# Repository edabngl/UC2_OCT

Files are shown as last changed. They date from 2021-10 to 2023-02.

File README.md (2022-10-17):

<p align="center">
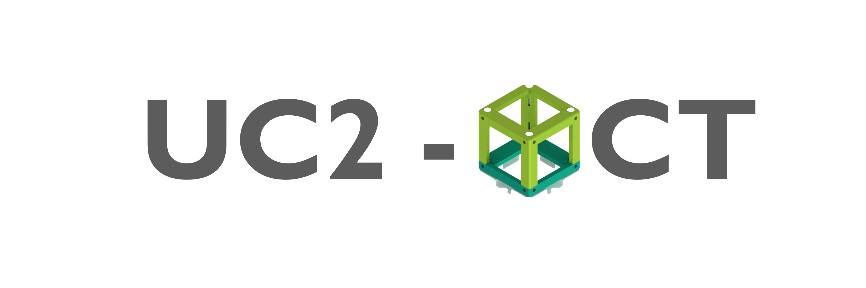
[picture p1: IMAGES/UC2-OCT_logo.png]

</p>

# Open-Source, Low-Cost, 3D-Printed, Full-Filled Time-Domain Optical Coherence Tomography using openUC2 Modular System
---
__*The project contents are still updating. Last update is in 17.10.2022.*__

This repository will help you to build and setup *UC2-OCT*.

In this project, we will design a open-source, low-cost, 3D-printed, Full-filled Time-domain Optical Coherence Tomography based on UC2 optical system.
The setup uses 3D-Printed inserts and cubes, Injection Molding (IM) cubes and cheap optical and electronic components. Some module designs were used directly from UC2-v3 designs, and some of them were redesigned for the UC2-OCT setup.

***Key Parameters of the UC2-OCT Project:***
* The system is Low-cost : 3D-Printed inserts, IM cubes and cheap components
  *  cheap Light Source (LaserLand RGB laser and Superlum SLD at 850 nm)
  *  cheap optical filters (Comar Longpass Filter)
  *  cheap Detector (RasPi camera and Raspi 4)
  *  cheap electronics (ESP-32S as microcontroller)
  *  low-cost, light Silver Mirror (DIY)
* Easy to assemble: 3D-printed cubic modular sytem
* Open-Source: UC2 based system and publishing all details online in GitHub repository
* 3D-Printed: UC2 based experimental setup

### THEORY

This section introduces the theoretical part of the *UC2-OCT* project. It will help you to understand the basic physics behind the setup. The setup is built using 3d-printed modular optical toolbox system openUC2. The details of the project is explained in its [GitHub](https://github.com/openUC2/UC2-GIT) repository in detail.

The basic parameteres of 3d-printed and IM base cubes are explained [here](https://github.com/openUC2/UC2-GIT/tree/master/CAD/ASSEMBLY_CUBE_Base). OCT is based on Michelson Interferometer system and it was already adapted and tested in [UC2](https://github.com/openUC2/UC2-GIT/tree/master/APPLICATIONS/APP_Michelson_Interferometer) design system.

##### Optical Coherence Tomography (OCT)

The following sketch demonstrates the basic OCT scheme based on time.
<p align="center">
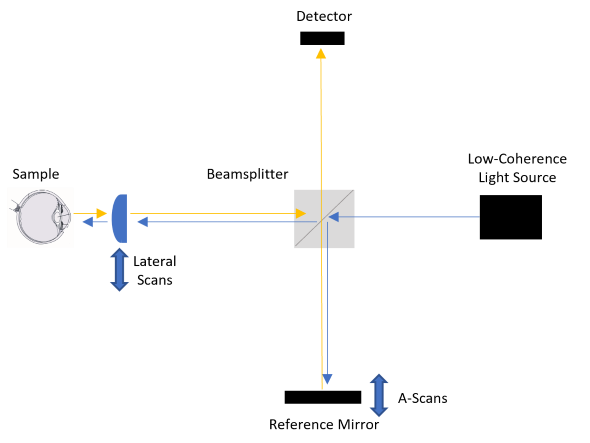
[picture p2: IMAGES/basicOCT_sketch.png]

</p>
##### Full-filled Optical Coherence Tomography (FF-OCT)
*Working Principle:* FF-OCT employs a 2-D image sensor like a CCD or CMOS camera as the detector, and en-face images of the sample are acquired at different depths by coherence gating.

* High axial and lateral resolutions are possible with FF-OCT.
* The use of FF-OCT in the time-domain configuration avoids specialized and potentially expensive components such as galvanometer or MEMS micromirror scanners, swept-sources and even superluminescent diode (SLED) or halogen or supercontinuum sources. Simple LEDs provide sufficient illumination for sub-10-μm imaging. Such a system has the potential to create high resolution 3D tomograms at very low cost.

REFERENCE:
Invented by Claude Boccara in 1998 (France).
Resolution: 1um in 3D

The full-filled OCT (FF-OCT) setup give an opportunity of recording en-face images of the sample when the Reference mirror moves in the z-axis. The movement mechanism of the sample Objective lens is not needed in time-domain designs and the technique enables the high-speed OCT scanning with its this advantage. The working mechanism of the FF-OCT can be shown in the figure below.

<p align="center">
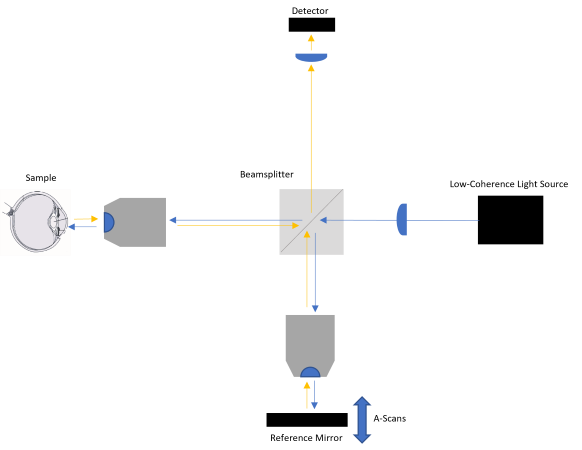
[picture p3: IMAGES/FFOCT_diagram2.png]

</p>

### UC2-OCT

*UC2-OCT Setup Diagram*

__Sketch 1__ describes the OCT system with red laser and SLD light sources.   The experimental procedure starts with the laser source and then switches to SLD source. Basic idea of aligning with Laser is the setting up the mirrors and objective lenses positions in Sample Arm and Reference arm using the advantage of the long coherence length of the laser source.
SLD diode is a low-coherence light. The aligned setup is directly used with NIR-SLD light source. The details of the setup design and experimental steps are explained in the [Experimental Process section](./1.Experimental_Process).

<p align="center">
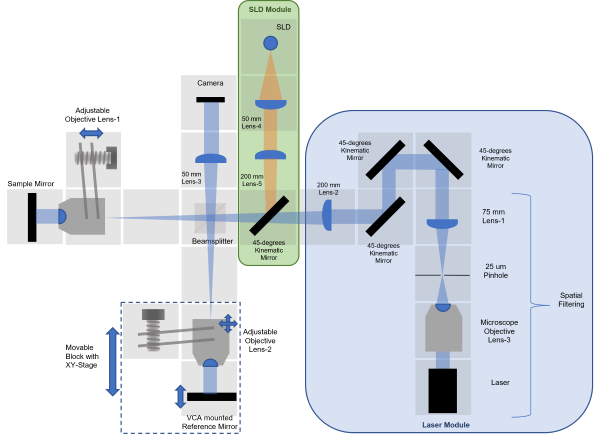
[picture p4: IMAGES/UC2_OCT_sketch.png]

</p>

*UC2-OCT Setup Diagram (adapted to Autodesk Inventor with UC2 modules)*

<p align="center">
<a href="#logo"
name="logo">
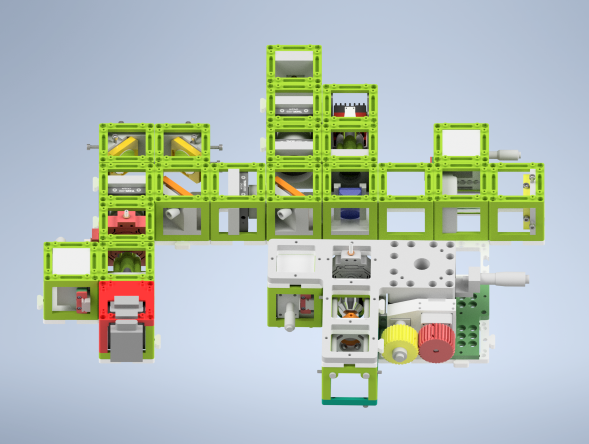
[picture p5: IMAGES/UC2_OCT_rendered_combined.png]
</a>
</p>

## Table of Content
  * **[1. Experimental Process](./1.Experimental_Process)**
    * **[Modules](./2.Experimental_Process/Modules)**
    * **[Alignment Procedure](./1.Experimental_Process/Alignment_Procedure)**
    + **[4. Bill of Materials](./1.Experimental_Process/Bill_of_Materials)**
  * **[2. Results](./2.Results)**

## Get Involved
This project is open so that anyone can get involved. You don't even have to learn CAD designing or programming.
You can directly connect with us using GitHub repository. Ask your questions or share your ideas with us!

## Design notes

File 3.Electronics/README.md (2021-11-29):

# Electronics

During the project, some electronic parts are using for various purposes.

Laser in the system is used for alignment of the mirrors.
LED is the light source of the setup.
Voice Coil Actuator (VCA) is used in different modules for linear motion of the sample in z direction and fine adjustment of the reference mirror.
Camera records the A-scan and B-scan images.

For more details, check the folder of each electronic parts.
* [LED Light Source](./3.Electronics/LED)
* [LASER](./3.Electronics/LASER)
* [SLED](./3.Electronics/SLED)
* [Voice Coil Actuator](./3.Electronics/Voice_Coil_Actuator)
* [Camera](./3.Electronics/Camera)

## Collaborating
If you find this project useful, please like this repository, follow us on Twitter and cite the webpage! :-)

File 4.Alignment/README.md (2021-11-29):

# Alignment Procedures

This repository will help you to build and alignment process of *UC2-OCT*.

*In this project, we will design a low-cost, 3D-printed, time-domain Optical Coherence Tomography based on UC2 system.*
We started to build our setup with basic version; Michelson Interferometer. Then, the setup will be adapted to the UC2 System with 3D-Printed inserts, Injection Molding (IM) cubes and cheap components.

## Alignment Procedure of Michelson Interferometer with Laser

I used different articles to follow in the alignment process.
_1st article_ is [](). In this article 2 important steps of the alignment process is explained in detail. Our aim is to see interference fringes. To make the process easier I prefered to used [RGB Laser](.../3.Electronics/LASER)

Reference Article: [An improved Michelson interferometer: smoothing out the rough spots for a more effective teaching tool - 2021](https://www.spiedigitallibrary.org/conference-proceedings-of-spie/10452/104521H/An-improved-Michelson-interferometer--smoothing-out-the-rough-spots/10.1117/12.226966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)

* 1st step is

_2nd technic_ is observing Fresnel Interference to obtain almost same arm distances for two mirrors.
(Rainer's suggestion)
Reference Article:[Fresnel Interference in the Michelson Interferometer - 1950](https://www.osapublishing.org/josa/abstract.cfm?uri=josa-40-11-787)

## Project Timeline:

| Date | To Do | Status of the Task |
| --- | --- | --- |
| **September 2021** | Using Thorlab equipments, Michelson Interferometer was built with a RGB Laser and Red paper filter. | `DONE` |

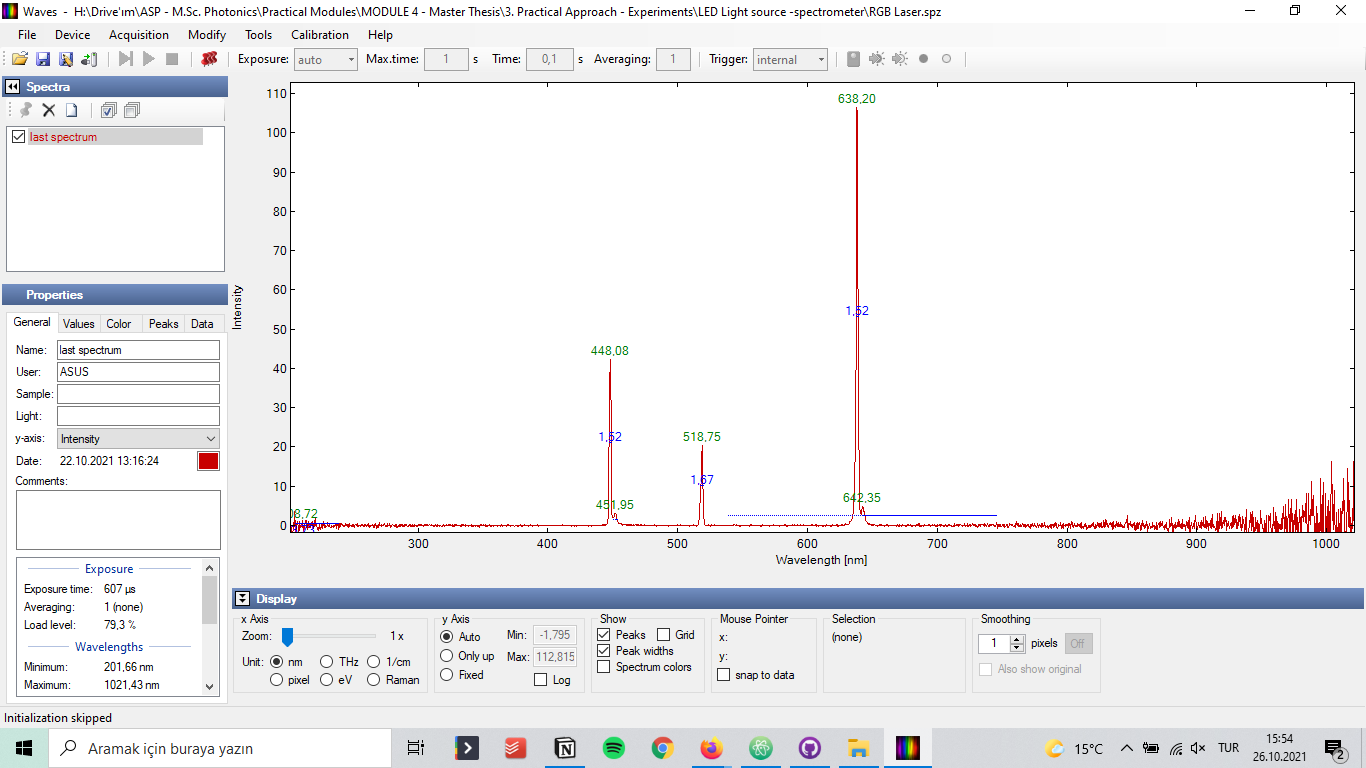
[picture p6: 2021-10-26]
1.Experimental_Process/Modules/1.Light Source Modules/1.LASER/IMAGES/RGB Laser spectrum.PNG

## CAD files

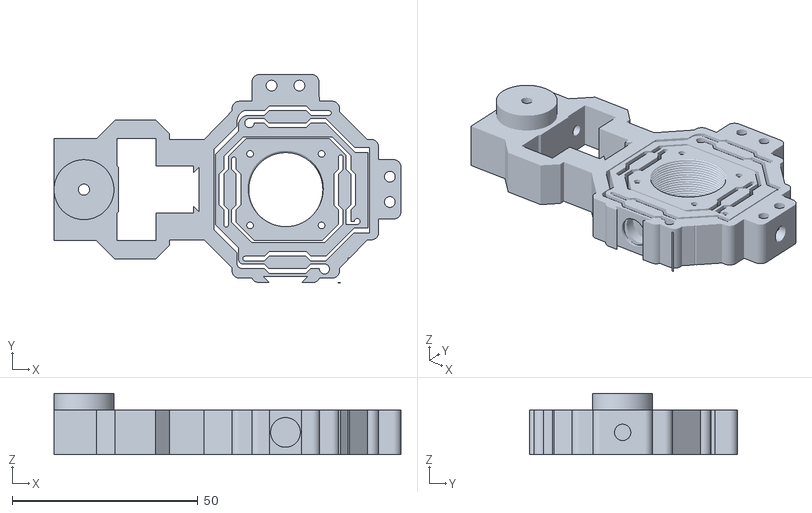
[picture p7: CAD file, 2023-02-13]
1.Experimental_Process/Modules/4.Adjustable Z Stage Modules/XZ directions/Assembly_Cube_Z_Stage_Objective_XY_Stage.stl
93.3 x 56.0 x 16.5

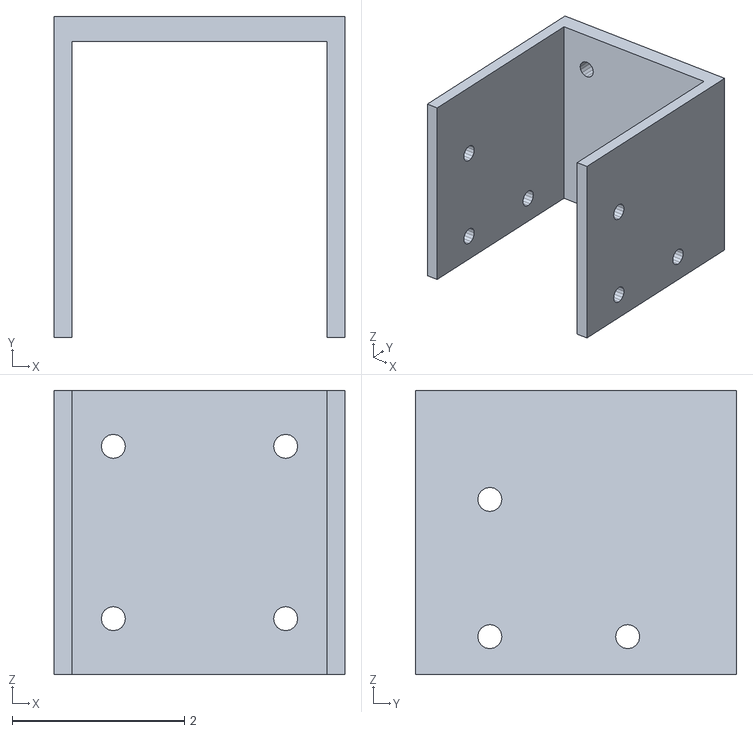
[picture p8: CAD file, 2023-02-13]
1.Experimental_Process/Modules/1.Light Source Modules/1.LASER/DESIGN FILES/Assembly_Cube_Laser_Multicolour_insert_v3.stl
3.37 x 3.73 x 3.30

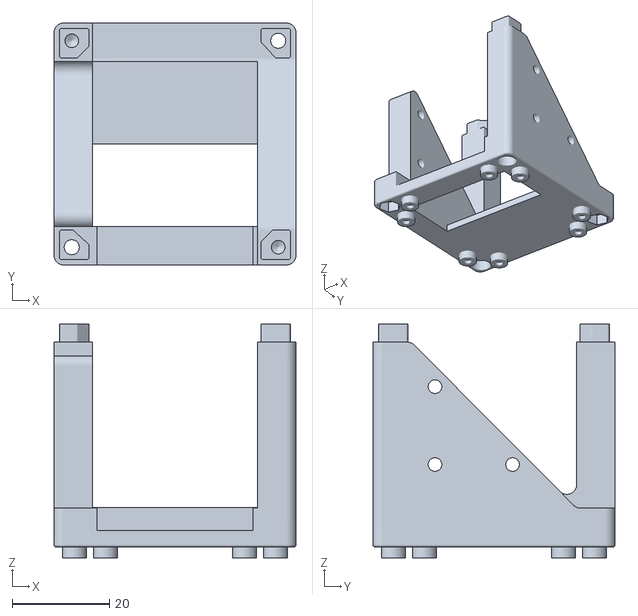
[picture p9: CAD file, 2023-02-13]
1.Experimental_Process/Modules/1.Light Source Modules/1.LASER/DESIGN FILES/20_Cube_Insert_Laser_multicolour_Lid_v3.stl
49.7 x 49.7 x 48.0

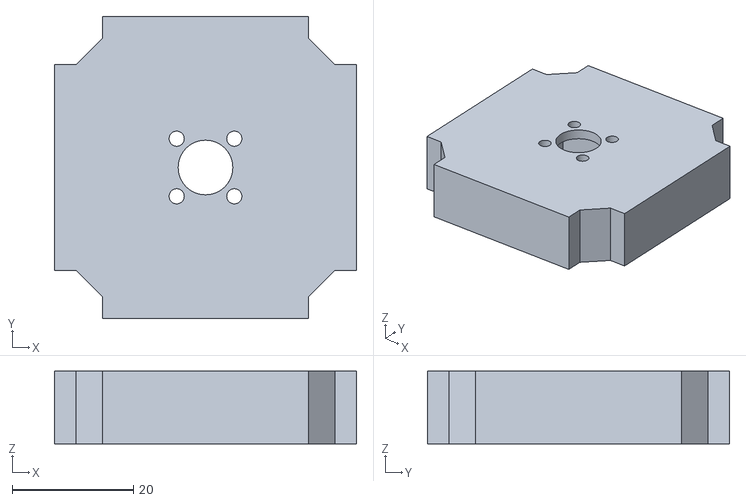
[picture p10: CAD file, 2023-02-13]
1.Experimental_Process/Modules/1.Light Source Modules/2.SLD/DESIGN FILES/20_Cube_Insert_Lasertack_mount_v3.stl
49.8 x 49.8 x 12.0

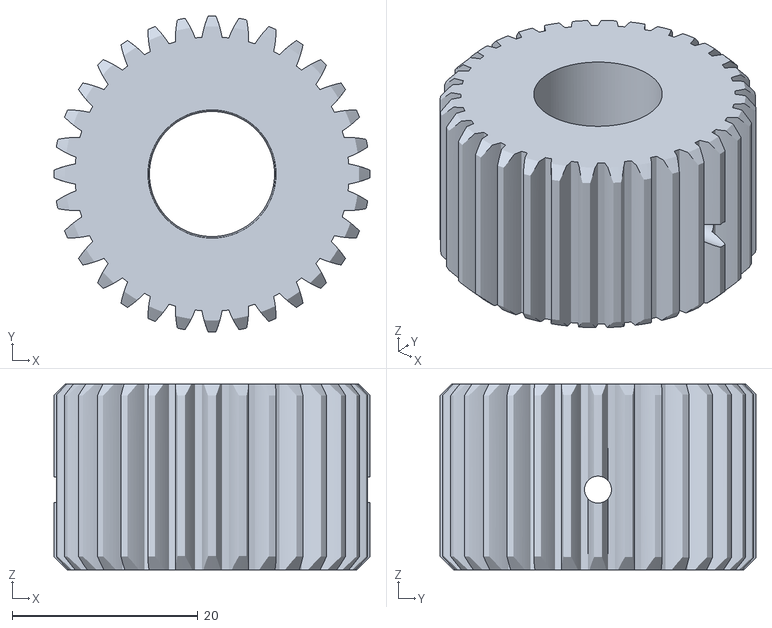
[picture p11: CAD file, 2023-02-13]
1.Experimental_Process/Modules/10.XY Linear Stage with Motors/30_cellSTORM_UC2_motorized_micrometer_gear2.stl
34.0 x 34.0 x 20.0

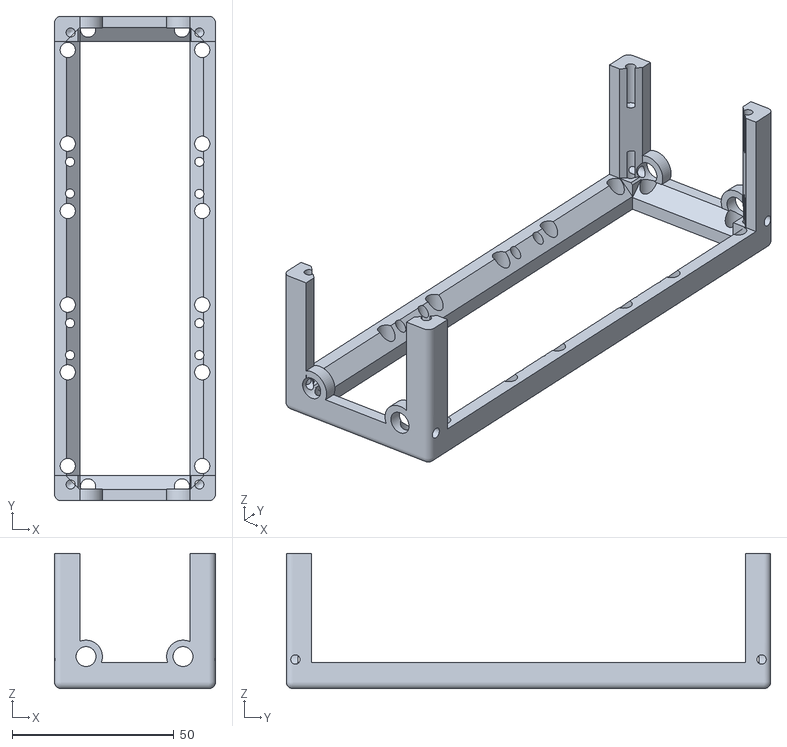
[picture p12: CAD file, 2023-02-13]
1.Experimental_Process/Modules/11.Base Cube and Others/10_Cube_3x1_with_rodes_v3.stl
49.8 x 149.8 x 41.8

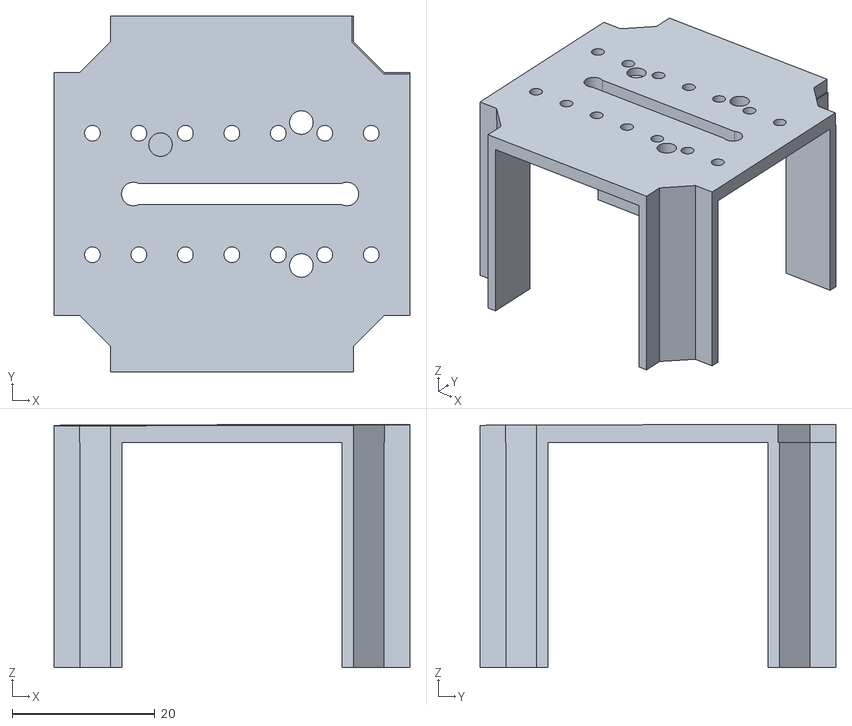
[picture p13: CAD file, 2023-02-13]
1.Experimental_Process/Modules/2.Camera Module/20_Cube_insert_AlliedVision_Alvium_v3.stl
49.8 x 49.8 x 34.0

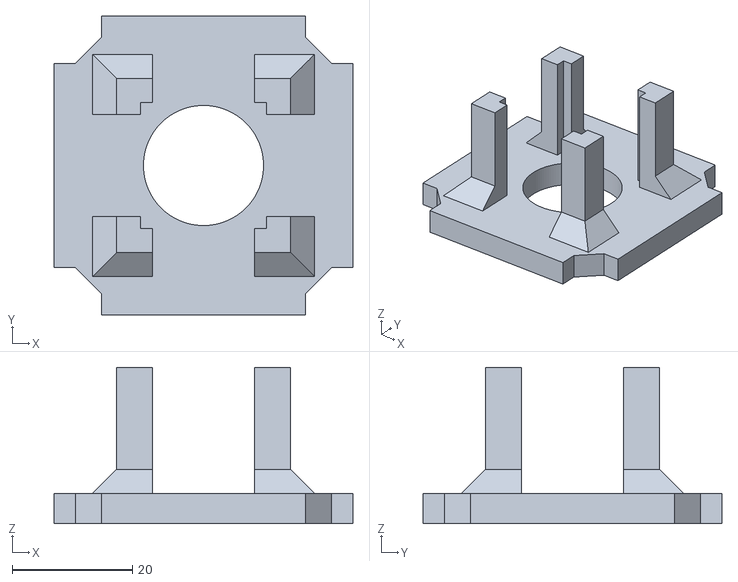
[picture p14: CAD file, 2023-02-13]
1.Experimental_Process/Modules/3.Beamsplitter Module/20_Cube_Insert_Beamsplitter_v3.stl
49.8 x 49.8 x 26.0

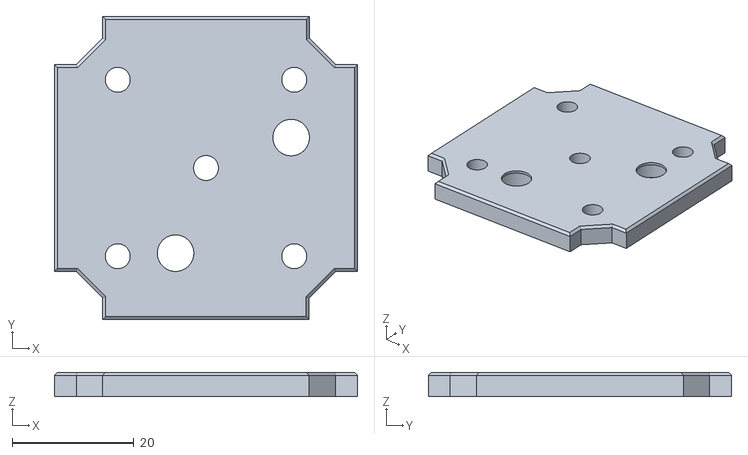
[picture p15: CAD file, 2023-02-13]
1.Experimental_Process/Modules/5.Sample Mirror Holder Module/20_Cube_Insert_Kinematic_Mirror_90_pro_magnetic_thin.stl
49.8 x 49.8 x 4.00

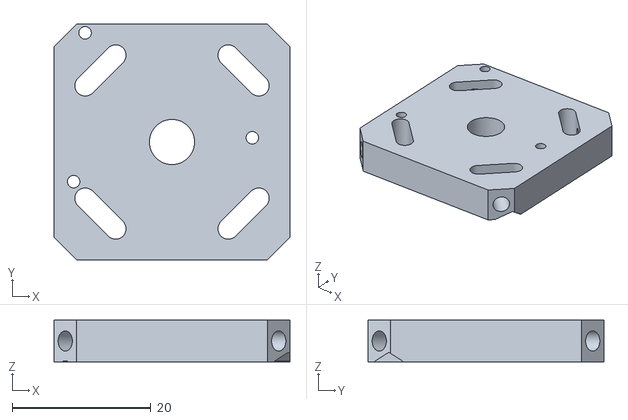
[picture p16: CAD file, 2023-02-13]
1.Experimental_Process/Modules/6.Reference Mirror Module/KES400 VCA/20_Cube_Insert_Kinematic_KES400_VCAmount__90_pro_v3_rod.stl
34.0 x 34.0 x 6.00

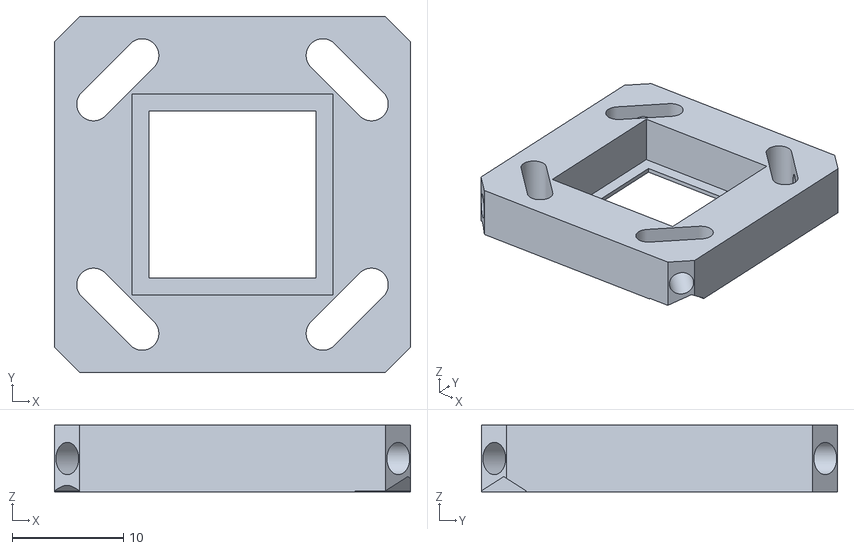
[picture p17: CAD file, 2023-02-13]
1.Experimental_Process/Modules/6.Reference Mirror Module/M12 VCA/20_Cube_Insert_Kinematic_M12_VCAmount__90_pro_v3.stl
32.0 x 32.0 x 6.00

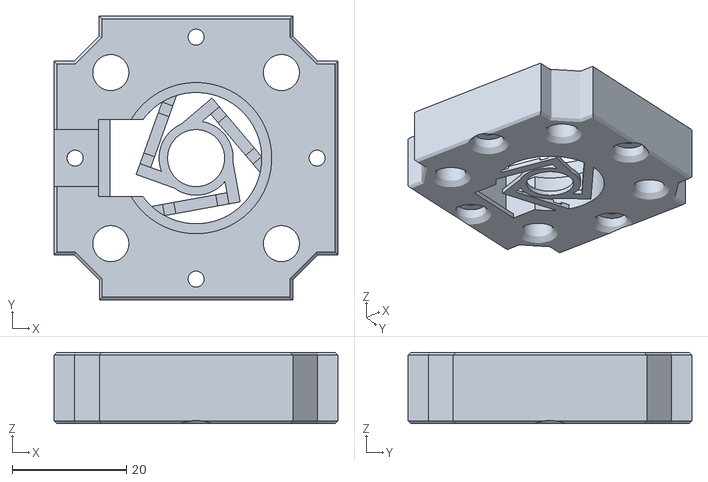
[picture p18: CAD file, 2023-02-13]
1.Experimental_Process/Modules/6.Reference Mirror Module/UC2 VCA/20_Cube_Insert_VCA_base_upper_v0.stl
49.8 x 49.8 x 12.5

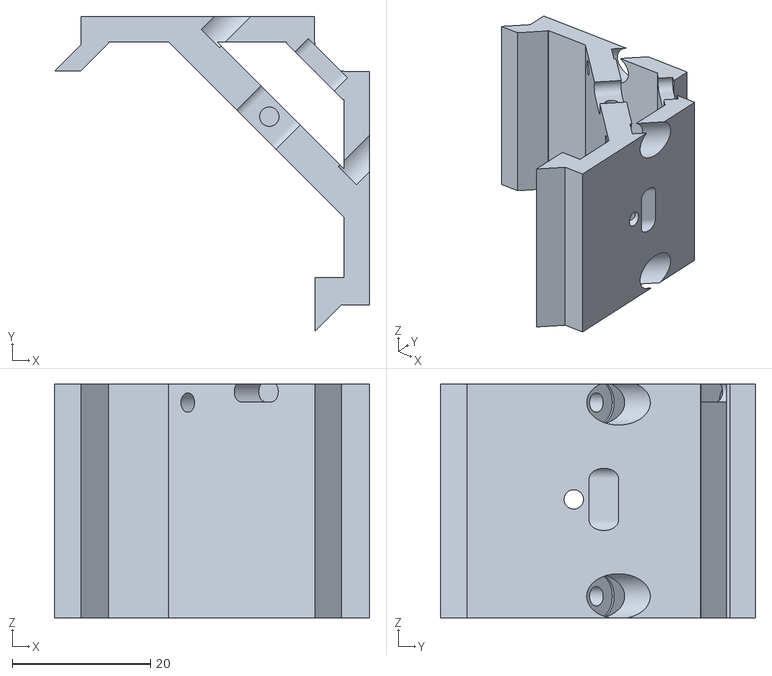
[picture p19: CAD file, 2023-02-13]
1.Experimental_Process/Modules/8.Kinematic Mirror Holder Module/20_Cube_Insert_Kinematic_Mirror_45_pro_v3.stl
45.5 x 45.5 x 33.8

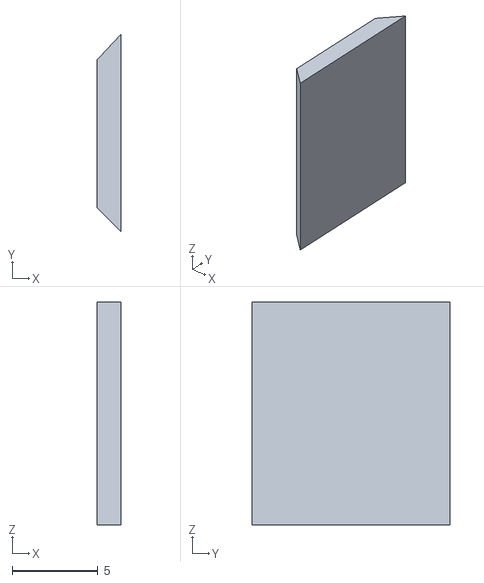
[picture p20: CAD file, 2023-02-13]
1.Experimental_Process/Modules/9.Pihnole Holder Module/20_Cube_Inser_Flexuremanipulator_springlock_v3.stl
1.40 x 11.5 x 13.0

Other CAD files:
1.Experimental_Process/Modules/10.XY Linear Stage with Motors/00_micrometer_moun_xystage_china_new.stl
1.Experimental_Process/Modules/11.Base Cube and Others/10_Lid_2x1_v3.stl
1.Experimental_Process/Modules/4.Adjustable Z Stage Modules/X direction/30_Cube_Z_Focus_NEMA8_captive_base_v0.stl
1.Experimental_Process/Modules/4.Adjustable Z Stage Modules/XZ directions/20_Cube_Insert_Z_Stage_XY_Stage_springblock.stl
1.Experimental_Process/Modules/1.Light Source Modules/1.LASER/DESIGN FILES/20_Cube_Insert_Laser_multicolour_Lid_v3.ipt
1.Experimental_Process/Modules/1.Light Source Modules/1.LASER/DESIGN FILES/Assembly_Cube_Laser_Multicolour_insert_v3.ipt
1.Experimental_Process/Modules/1.Light Source Modules/2.SLD/DESIGN FILES/20_Cube_Insert_Lasertack_mount_v3.ipt
1.Experimental_Process/Modules/10.XY Linear Stage with Motors/00_NEMA11.ipt
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

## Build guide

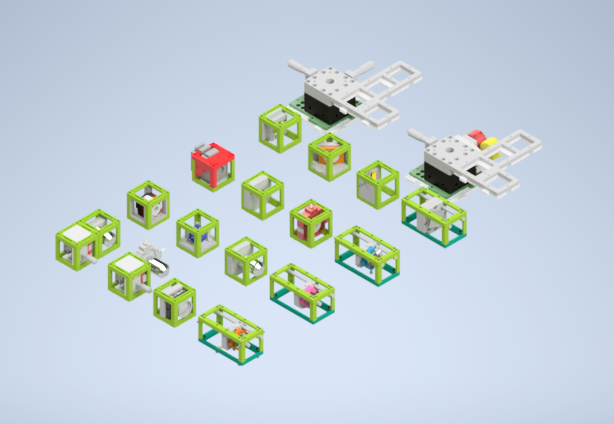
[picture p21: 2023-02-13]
1.Experimental_Process/Modules/IMAGES/Assembly_UC2_OCT_Modules.png

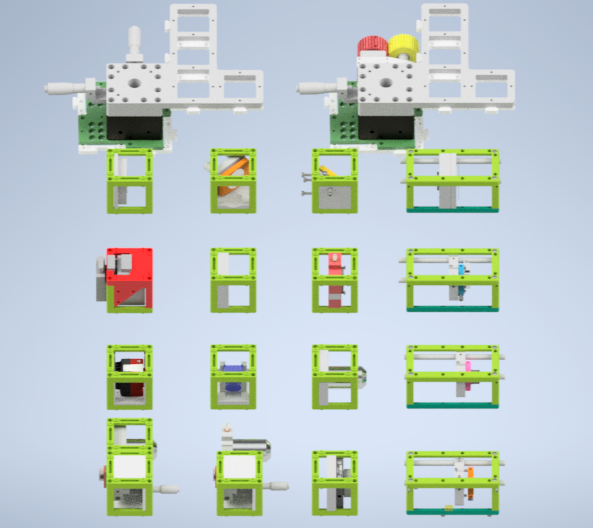
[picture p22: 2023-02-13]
1.Experimental_Process/Modules/IMAGES/Assembly_UC2_OCT_Modules_2.png

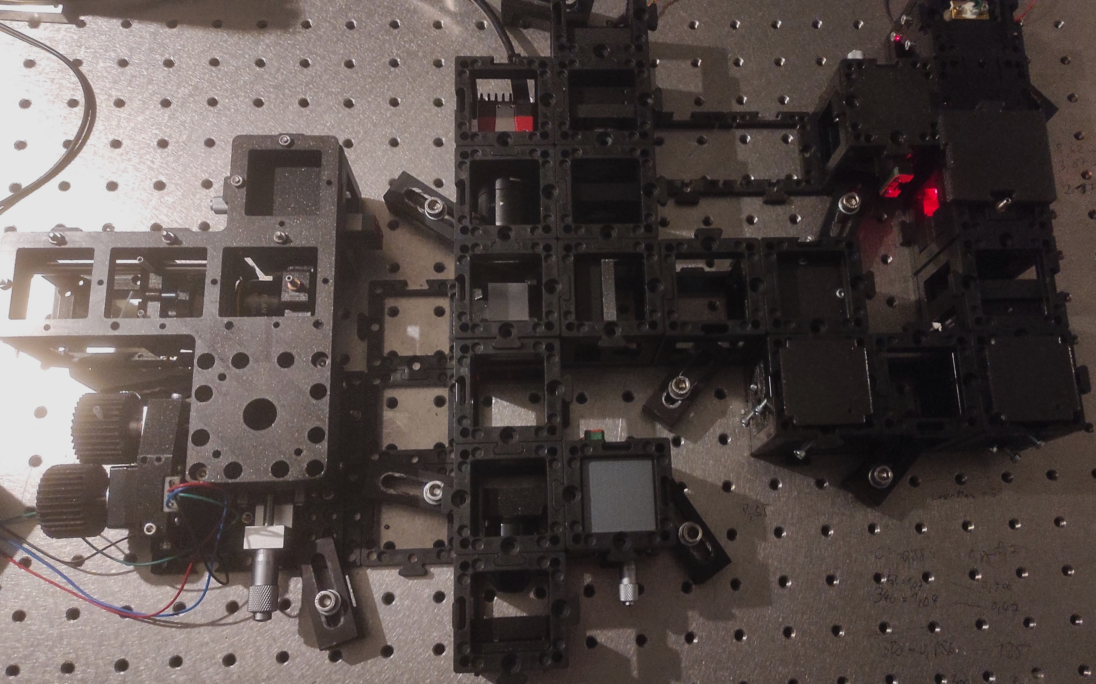
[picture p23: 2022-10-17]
2.Results/IMAGES/RES_alg_step4.jpg

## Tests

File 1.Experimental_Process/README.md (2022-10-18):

#open UC2-OCT: Full-filled Time-domain, Low Cost, 3D printed Optical Coherence Tomography

### Modules

<p align="center">

</p>,

### Electronics

During the project, some electronic parts are using for various purposes.

Laser in the system is used for alignment of the mirrors.
LED is the light source of the setup.
Voice Coil Actuator (VCA) is used in different modules for linear motion of the sample in z direction and fine adjustment of the reference mirror.
Camera records the A-scan and B-scan images.

For more details, check the folder of each electronic parts.
* [LASER](./Modules/1.Light Source Modules/1.LASER)
* [SLED](./Modules/1.Light Source Modules/2.SLD)
* [Voice Coil Actuator](./Modules/6.Reference Mirror Module/Voice_Coil_Actuator)
* [Linear Stage with NEMA motor](./Modules/1.Light Source Modules)
* [Camera](./Modules/2.Camera Module)

### Bill of material

## Collaborating
If you find this project useful, please like this repository, follow us on Twitter and cite the webpage! :-)

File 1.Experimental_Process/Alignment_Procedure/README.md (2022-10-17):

# Alignment Procedures

This repository will help you to build and alignment process of *UC2-OCT*.

*In this project, we will design a low-cost, 3D-printed, time-domain Optical Coherence Tomography based on UC2 system.*
We started to build our setup with basic version; Michelson Interferometer. Then, the FF-TD-OCT setup will be adapted to the UC2 System with 3D-Printed inserts, Injection Molding (IM) cubes and low-cost components.

## Alignment Procedure of Michelson Interferometer with Laser

Experimental Sketch of UC2-Oct with different light sources with the order of alignment procedure;

1st Configuration is with Laser light source and focusing light beams onto the Reference and Sample Mirrors.

<p align="center">

</p>

2nd Configuration is with Laser light source and additional lens after laser module. It's illuminating light beams parallel onto the Reference and Sample Mirrors.

<p align="center">

</p>

3rd Configuration is with LED light source. Firstly, the light beam is illuminated to Beamsplitter cube with an Köhler Illumination. Light is focused on the back focal plane of the objective lenses (it will be like that? check the configuraton again!!!!).

<p align="center">

</p>

#### Previous Method

I used different articles to follow in the alignment process.
_1st article_ is [](). In this article 2 important steps of the alignment process is explained in detail. Our aim is to see interference fringes. To make the process easier I prefered to used [RGB Laser](.../3.Electronics/LASER)

Reference Article: [An improved Michelson interferometer: smoothing out the rough spots for a more effective teaching tool - 2021](https://www.spiedigitallibrary.org/conference-proceedings-of-spie/10452/104521H/An-improved-Michelson-interferometer--smoothing-out-the-rough-spots/10.1117/12.226966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)

* 1st step is

_2nd technic_ is observing Fresnel Interference to obtain almost same arm distances for two mirrors.
(Rainer's suggestion)
Reference Article:[Fresnel Interference in the Michelson Interferometer - 1950](https://www.osapublishing.org/josa/abstract.cfm?uri=josa-40-11-787)

##### 1st SETUP: Michelson Interferometer Experiment Setup with Thorlabs Equipment - for practicing :)

##### 2nd SETUP: Michelson Experiment Setup with UC2 IM unit blocks
**Setup with a Laser as a Light Source and VCA:**
<p align="center">

</p>

### 3rd SETUP: Time-Domain OCT with SLED
**Setup with SLED as a Light Source and VCA:**
<p align="center">

</p>

### 4th SETUP: Time-Domain OCT with Red LED and Filter
**Setup with Red LED as a Light Source (with filter) and VCA:**
<p align="center">

</p>

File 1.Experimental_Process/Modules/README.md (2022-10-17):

Hardware Part of UC2-OCT is built by 3D-printed UC2 modules. Some of the modules are already used in the previous UC2 applications.
Some of the parts are designed for this application or redesigned for some parts.

Components of 3D-printed Part of the Setup:

  1. [Light Source Module](./Modules/Light Source)
  2. [Reference Mirror Module](./Modules/Reference Mirror Module)
  3. [Sample Module](./Modules/Sample Holder Module)
  4. [Beam Splitter Module](./Modules/Beam Splitter Module)
  5. [Camera Module](./Modules/Camera Module)
  6. 2 x [Objective Lens Modules](./Modules/Objective Lens Module)
  7. 

### 3D printing files

  All these files need to be printed. We used a Prusa i3 MK3 using PLA Prusament (Galaxy Black) at layer height x.x mm and infill xx%.
  The original design files are in the [INVENTOR](./INVENTOR) folder.
  The files for 3D-printing are in the [STL](./STL) folder.

  |  Type | Details  |  Amount | Price | Link  |
  |---|---|---|---|---|
  | Star LED Cage Holder |  *It holds star LED light source* |  1  |  x,xx € | [Design File](./INVENTOR)  | [Part.stl](./STL/)  |
  | Star LED Cage Holder Top |  *It covers top of the cage design* |  1  |  x,xx € | [Design File](./INVENTOR)  | [Part.stl](./STL/) |
  | [Beam Splitter Cube Holder](.\Modules\Beam Splitter Module) |  *It splits incoming light into two part and recombine them* |  1  |  x,xx € | [Design File](./INVENTOR)  | [Part.stl](./STL/) |
  | Kinematic Mirror Holder |  *It holds Reference Mirror* |  1  |  x,xx € | [Design File](./INVENTOR)  | [Part.stl](./STL/) |
  | Automated Kinematic Mirror Holder |  *It holds Sample Mirror with 3 Voice Coil Actuators* |  1  |  x,xx € | [Design File](./INVENTOR)  | [Part.stl](./STL/) |
  | Objective Lens Holder |  *It holds Objective Lens* |  2  |  x,xx € | [Design File](./INVENTOR)  | [Part.stl](./STL/) |
  | Camera Holder |  *It holds RasPi Camera* |  1  |  x,xx € | [Design File](./INVENTOR)  | [Part.stl](./STL/) |
  | [Circular Aperture Module](https://github.com/openUC2/UC2-GIT/tree/master/CAD/ASSEMBLY_CUBE_Aperture_Circular) |  *It holds* |  1  |  x,xx € | [Design File](./INVENTOR)  | [Part.stl](./STL/) |
  | [Dichroic Beam Splitter Module](https://github.com/openUC2/UC2-GIT/tree/master/CAD/ASSEMBLY_CUBE_Dichroic_Beamsplitter) |  *It holds* |  1  |  x,xx € | [Design File](./INVENTOR)  | [Part.stl](./STL/) |

### Additional parts
  This is used in the current version of the setup

  |  Type | Details  |  Amount | Price | Link  |
  |---|---|---|---|---|
  | Star LED | *Incoherent, low-cost light source* |  1  |  xx € | [My favourite online shop]()  |
  | Beam Splitter | *Beam splitter used in Thorlabs System* |  1 |  xx € | [My favourite online shop]()  |
  | Beam Splitter Cube | *Beam splitter used in UC2 System* |  1 |  xx € | [My favourite online shop]()  |
  | Protected Silver Mirrors | *Thorlabs Mirrors used in UC2 System* |  2  |  xx € | [Thorlabs]()  |
  | Mirror | *Mirror for Sample Mirror Module used in UC2 System* |  2  |  xx € | [DIY]()  |
  | Objective Lens | *Objective Lenses* |  2  |  xx € | [My favourite online shop]()  |
  | Dichroic Longpass Filter | *It increases the coherence length of the LED* |  1  |  xx € | [Comar]()  |

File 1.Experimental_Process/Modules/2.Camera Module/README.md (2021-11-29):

# Camera Module

In this part, we descbribe how the Raspberry Camera is connected to the system and used. Details about connection of the camera and setting up the Rapsberry Pi 4 can be found in UC2-GIT [RasPi Camera Module](https://github.com/openUC2/UC2-GIT/tree/master/CAD/ASSEMBLY_CUBE_RaspiCam) and [Setting up Raspberry Pi.](https://github.com/openUC2/UC2-Software-GIT/blob/master/GUI/RASPBERRY_PI/README.md)

<p align="center">
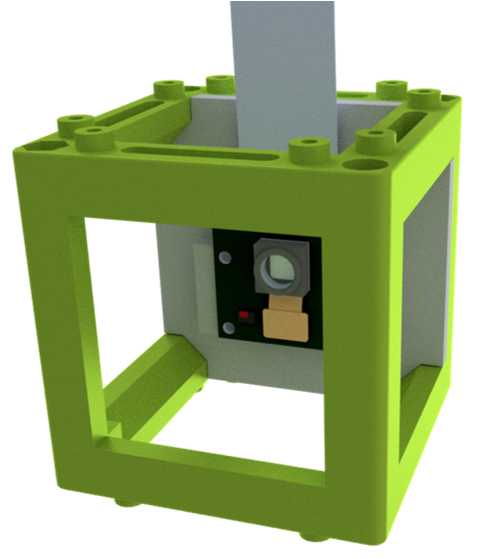
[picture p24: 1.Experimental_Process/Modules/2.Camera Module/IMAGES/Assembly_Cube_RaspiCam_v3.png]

</p>

We are using Raspberry Pi Camera Module v2 from [Okdo.](https://www.okdo.com/p/official-raspberry-pi-camera-v2-1/)

* It attaches via a 15cm ribbon cable to the CSI port on the Raspberry Pi.
* The camera works with all models of Raspberry Pi 1, 2, 3 and 4.

Installation Guide of the RasPi camera can be found [here.](https://www.raspberrypi.com/documentation/accessories/camera.html) in details.

| Hardware Specifications | Camera Module v2 |
| --- | --- |
| **Net price** | $25 |
| **Weight** | 3g |
| **Still resolution** | 8 Megapixels |
| **Video modes** | 1080p30, 720p60 and 640 × 480p60/90 |
| **Sensor** | Sony IMX219 (high-speed video imaging and high sensitivity)|
| **Sensor resolution** | 3280 × 2464 pixels |
| **Sensor image area** | 3.68 x 2.76 mm (4.6 mm diagonal) |
| **Pixel size** | 1.12 µm x 1.12 µm |
| **Optical size** | 1/4" |
| **Focal length** | 3.04 mm |
| **Horizontal field of view** | 62.2 degrees |
| **Vertical field of view** | 48.8 degrees |
| **Focal ratio (F-Stop)** | 2.0 |

| Software Features | Camera Module v2 |
| --- | --- |
| **** |  |
| **** |  |
| **** |  |
| **** |  |
| **** |  |

Camera *raspistill* codes are listed [here.](https://www.raspberrypi.com/documentation/accessories/camera.html#raspistill)

## Basic RasPi Camera Codes for Terminal
There are various ways the cameras can be used. The simplest option is to use one of the provided camera applications, such as libcamera-still or raspistill.

* Activating RasPi Camera:  
      raspistill -k
* Activating RasPi Camera for a time:

* Taking Picture:
      raspistill -o ~/Pictures/first_image.jpg

*-o* is the option to specify an output file name. Here o is the abbreviation for output.   
*~/Pictures/first_image.jpg* is the path + file name for saving the picture. “~” means that we’ll start from the home directory (from the user you’re connected as), then we have *“/Pictures/”* to go in the Pictures directory of that user, and finally *“first_image.jpg”* is the file name.     
I have used a “.jpg” extension here, you can also use other common image extensions such as “.png”. Don’t forget the extension otherwise you might have trouble opening the file if you share it for example on a Google Drive or on Windows.

You can also provide a relative path to save the picture from where you are in the terminal.   

      $ cd ~/Pictures/
      $ raspistill -o second_image.jpg

* Editing Photo settings with commands:  
Let’s try one command to change the resolution, flip the image vertically, and wait 2 seconds instead of 5.

      $ raspistill -o ~/Pictures/new_image.jpg -w 1280 -h 720 -vf -t 2000

Let’s break this command down:
  * raspistill: the command to take a picture.
  * -o ~/Pictures/new_image.jpg: the option to add an output file name, as previously seen.
  * -w 1280 -h 720: to set the resolution you have to provide 2 options. –w for the width in pixels, and –h for the height in pixels.
  * -vf: this option will vertically flip the picture.
  * -t 2000: this is the timeout option. Basically, once you execute the raspistill command in the terminal, it will wait for x amount of milliseconds before taking the picture and exiting. By default the amount is 5 seconds, or 5000 milliseconds. Here we choose 2000, which means 2000ms or 2 seconds. Make sure to always provide a duration in milliseconds for that option.

* Applying filters to Pi camera
  * -co -10: this will reduce the contrast a little bit. The contrast setting goes from -100 to 100, default to 0 (no change).
  * -br 55: increase the brightness a little bit. The brightness setting goes from 0 and 100, default to 50.
  * -sa -10: decrease the saturation. The saturation setting goes from -100 to 100, default to 0.

* Adding text to the photo
If you want to add some text on your photo, you can do so with the -a option. For example:

      -a "Hello from the Pi camera"

More details can be found [here.](https://roboticsbackend.com/raspberry-pi-camera-take-picture/)

## Ready-to-use Camera Module

<p align="center">
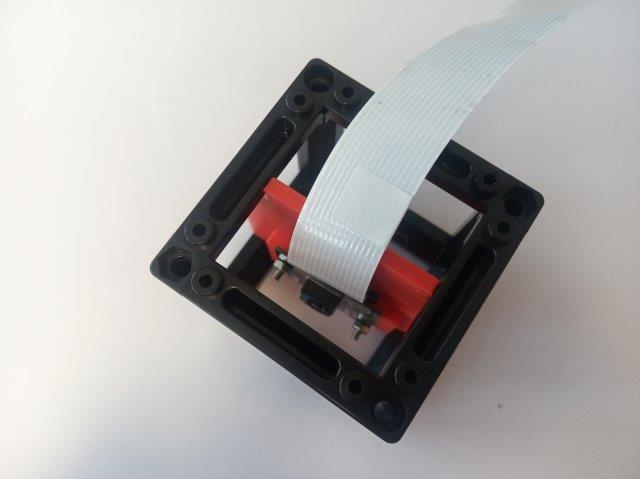
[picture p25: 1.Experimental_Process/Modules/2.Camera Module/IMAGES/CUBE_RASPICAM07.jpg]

</p>

## Collaborating
If you find this project useful, please like this repository, follow us on Twitter and cite the webpage! :-)

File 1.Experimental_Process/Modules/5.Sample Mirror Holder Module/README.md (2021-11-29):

# Sample Mirror Module

Below we describe how the Sample Mirror Module in UC2 system can be build and assembled in order to replicate the whole system as shown in the rendering above.

Incoming light beam are split into two part with Beam-splitter Module. Beams travel into two different path. These beams pass through the objective lenses and focuses on the reference mirror and sample mirror. In this section, we are giving more details about Sample Mirror Module.

In Thorlabs System, protected silver mirror was used in the reference and sample arm. The module with Thorlabs component is shown in the next image:

<p align="center">

</p>

But this mirror is heavy to use in 3D-printing system and we searched some methods to obtain light slver coated mirror which is moved by voice coil actuator.

## Thin Lightweight Silver or Gold Coated Mirror
The idea is the coating of microscope cover slip with gold (in IPHT clean room) or gold in the lab.

<p align="center">
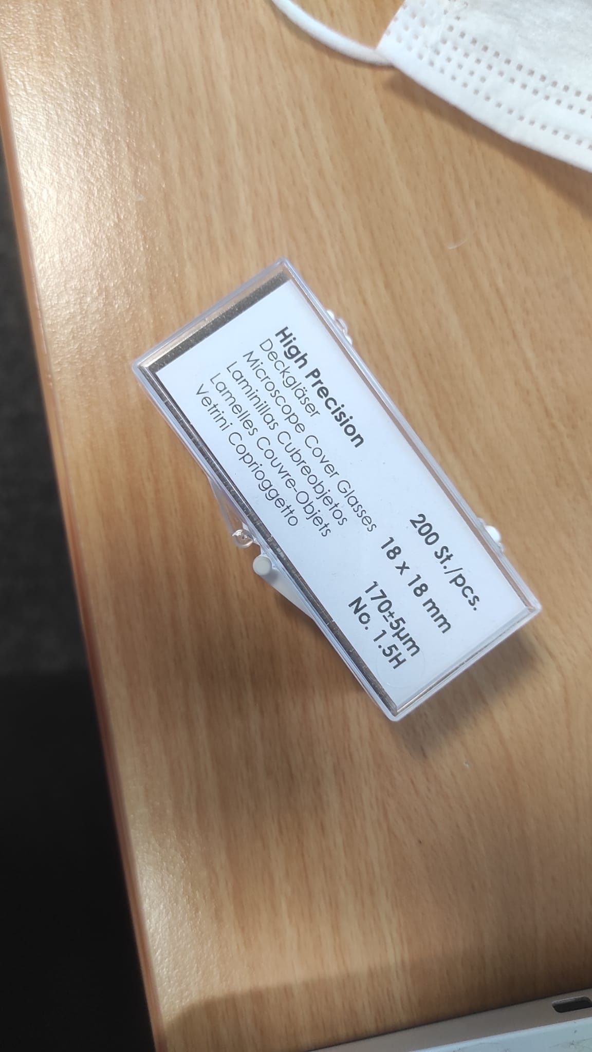
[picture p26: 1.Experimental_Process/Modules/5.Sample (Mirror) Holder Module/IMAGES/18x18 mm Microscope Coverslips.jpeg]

</p>

<p align="center">
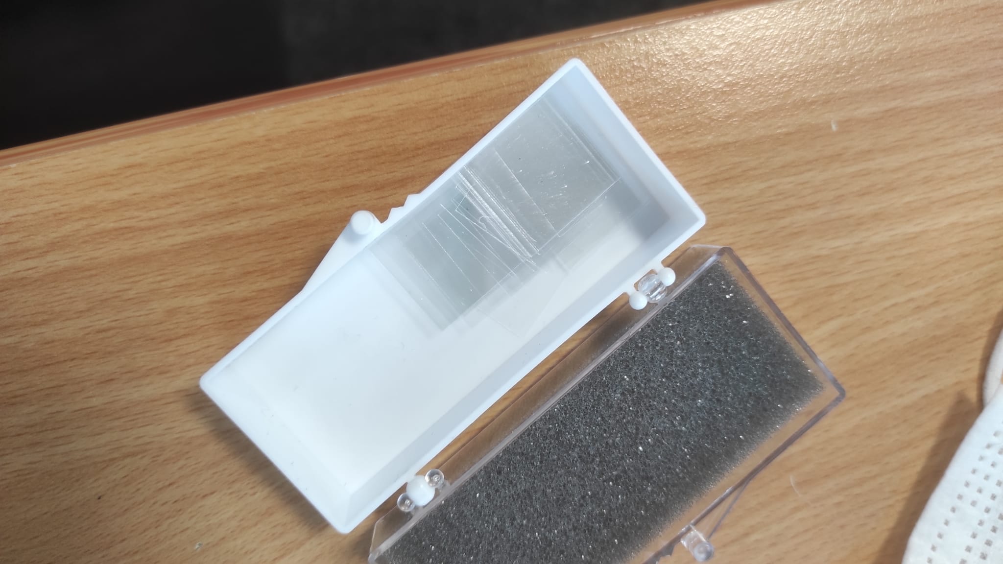
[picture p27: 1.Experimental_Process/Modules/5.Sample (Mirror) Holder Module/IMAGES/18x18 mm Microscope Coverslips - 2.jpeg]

</p>

## Kinematic Mirror Mount design
We needed a new design for this system.

Reference Artcile for mount Design: [3D printable optomechanical cage system with enclosure](https://www.researchgate.net/publication/322078822_3D_printable_optomechanical_cage_system_with_enclosure)

### 3D printing files

  All these files need to be printed. We used a Prusa i3 MK3 using PLA Prusament (Galaxy Black) at layer height x.x mm and infill xx%.
  The original design files are in the [INVENTOR](./Hardware/INVENTOR) folder.
  The files for 3D-printing are in the [STL](./Hardware/STL) folder.

  |  Type | Details  |  Amount | Price | Link  |
  |---|---|---|---|---|
  | Kinematic Mirror Holder |  *It holds Reference Mirror* |  1  |  x,xx € | [Design File](./Hardware/INVENTOR)  | [Part.stl](./STL/)  |

### Additional parts
  This is used in the current version of the setup

  |  Type | Details  |  Amount | Price | Link  |
  |---|---|---|---|---|
  | Mirrors | *Thorlabs Protected Silver Mirrors used in Thorlabs System and UC2 System* |  2  |  xx € | [My favourite online shop]()  |
  | Screws | *For alignment of the Mirror* |  3  |  xx € | [My favourite online shop]()  |
  | Magnets | *For alignment of the Mirror* |  3  |  xx € | [My favourite online shop]()  |

In Thorlabs System, two mirrors are used both optical path. In 3D-printed version, one silver mirror is used only for Reference Mirror Module.

*Properties of the Thorlabs Protected Silver Mirror*

### Assembly of the Module
Assembly part are related to UC2 System. In this section, we describes how a 3D-printed Kinematic Mirror Module is assembled.

***1.*** *These are the parts needed for the the module.*

<p align="center">

</p>

***2.*** *Start by ...*

<p align="center">

</p>

***2.*** *Continue with ...*

<p align="center">

</p>

***2.*** *DONE! LOOK AT THE BEAUTY!*

<p align="center">

</p>

## Showcase
*AWESOME RESULTS!*

<p align="center">

</p>

***Fig 1.*** *MY MOST AWSOME IMAGE*

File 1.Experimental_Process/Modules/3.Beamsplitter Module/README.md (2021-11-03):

# Beam Splitter Module

Below we describe how the Beam Splitter Module in UC2 system can be build and assembled in order to replicate the whole system as shown in the rendering above.

<p align="center">
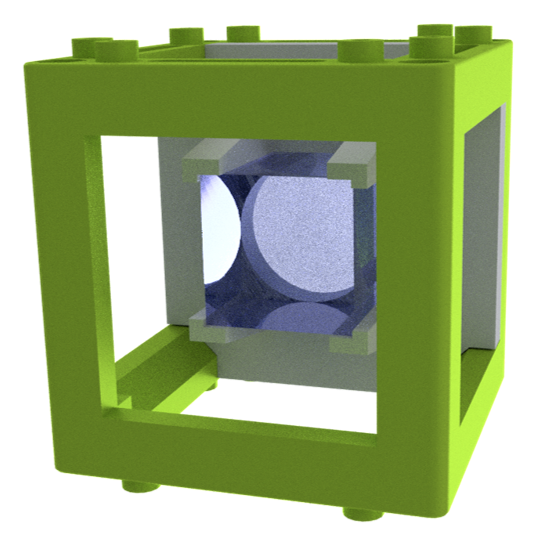
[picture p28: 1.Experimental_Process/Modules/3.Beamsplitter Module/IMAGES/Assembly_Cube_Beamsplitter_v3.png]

</p>

More details about the 3D-printing, assembling and setting up can be found in [UC2-GIT](https://github.com/openUC2/UC2-GIT/tree/master/CAD/ASSEMBLY_CUBE_Beamsplitter) repository in detail.

## Ready-to-use Beam Splitter Module

<p align="center">
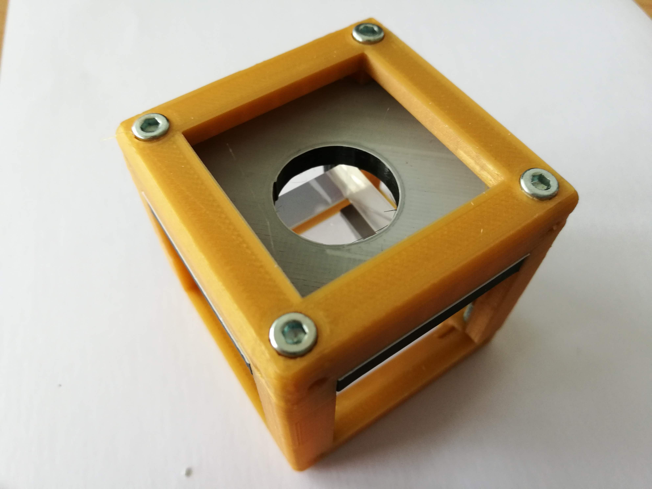
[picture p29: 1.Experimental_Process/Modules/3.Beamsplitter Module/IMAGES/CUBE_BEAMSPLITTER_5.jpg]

</p>

## Beam Splitter Component in Thorlabs system

Thorlabs Beamsplitter is used in the setup.
* Non-Polarizing
* 50:50
* Size : 25 x 36 mm
* Product Catalog Code: BSW10R
* Coating: 400 - 700 nm

More details can be found [here](https://www.thorlabs.com/thorproduct.cfm?partnumber=BSW10R).
<p align="center">
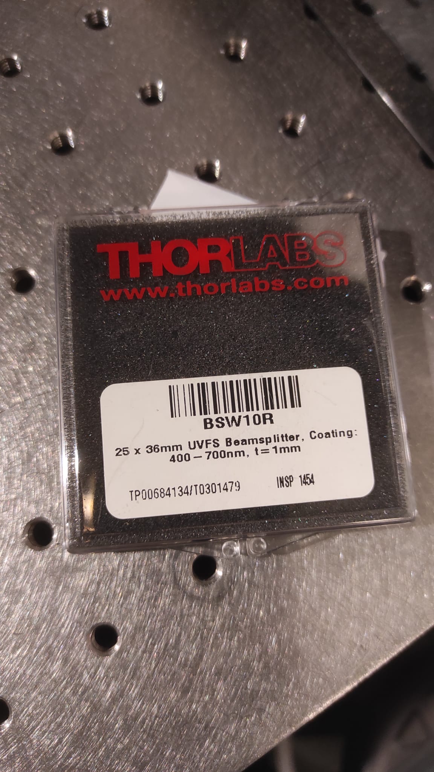
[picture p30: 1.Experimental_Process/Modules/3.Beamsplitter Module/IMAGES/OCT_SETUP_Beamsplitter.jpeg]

</p>

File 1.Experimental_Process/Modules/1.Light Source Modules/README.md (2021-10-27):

During the project, different type of low-cost light sources were used for different purposes: [LASER]() and [LED]().

### Coherence of The Light sources

#### LASER

Pen-lasers were used in the beggining for the alignment , blue UV and green VIS lasers. Green laser was so powerful. I tried to reduce the power using ND filter but instead of that I changed the laser.

In the alignment part of the Thorlabs setup, [RGB Laser source]() was used with red paper filter.

* More details and connection information of the RGB Lasers can be found [here.](.../Electronics/LED)

#### LED

After alignment of the mirrors in the setup,laser illumination part was changed with [red LED light source]() + [long-pass filter]() + [Köhler illumination module](.../Köhler Illumination).

Spectrum of the red LED:

<p align="left">
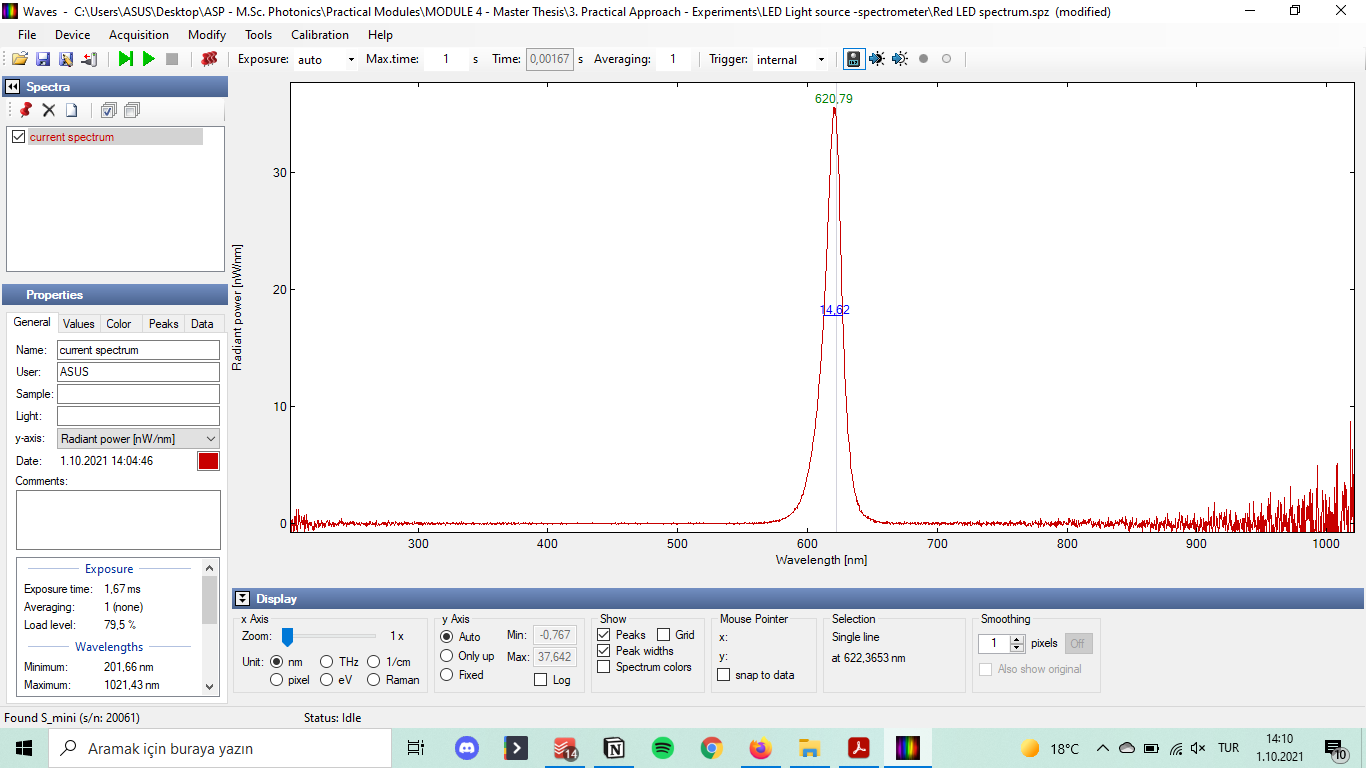
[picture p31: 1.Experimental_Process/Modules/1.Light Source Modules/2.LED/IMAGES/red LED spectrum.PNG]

</p>

* More details and connection information of the LED can be found [here.](.../Electronics/LED)

## Dichroic Longpass filter

A I mentioned below, the coherence length of the light source is the key parameter for the OCT system. When we use cheap incoherent light source, it is low-coherence length and hard to see interference fringes in the system.
To increase the coherence length of the light source, long-pass filter is a good option.

We used Comar Dichroic Longpass Filter. The spectrum of the filter is shown here:
<p align="left">

</p>

More details can be found [here]().

Spectrum of the red LED with dichroic long pass filter:
<p align="left">

</p>

FWHM decreases to .....
So coherence length of the LED becomes .....

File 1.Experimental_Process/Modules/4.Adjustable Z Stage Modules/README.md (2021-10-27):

# Objective Lens Module

Below we describe how the Objective Lens Module can be build and assembled in order to replicate the whole system as shown in the rendering above.

<p align="center">

</p>

2 objective lenses are used in the system. Incoming light beam are split into two part with Beam-splitter Module. Beams travel into two different path. These beams pass through the objective lenses and focuses on the next optical elements ( reference mirror and sample or sample mirror).

*Properties of the objective lenses*
  Objective Lens 1:
  Objective Lens 2:

More details about the 3D-printing, assembling and setting up can be found in [UC2-GIT]() repository in detail.

## Ready-to-use Objective Lens Module
<p align="center">

</p>

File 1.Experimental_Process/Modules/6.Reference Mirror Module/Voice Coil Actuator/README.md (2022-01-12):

# VOICE COIL ACTUATOR

Voice Coil Actuator is used in the UC2-OCT system to move the sample or sample mirror in z direction in um scale.
It can be used for the alignment of the reference mirror with using 3 voice coil actuators in three corners of the mirror holder to obtain fine alignment in low coherence light source setups.

## PWM (Pulse Width Modulation)

Pulse Width Modulation, or PWM, is a technique for getting analog results with digital means. Digital control is used to create a square wave, a signal switched between on and off. This on-off pattern can simulate voltages in between the full Vcc of the board (e.g., 5 V on Uno, 3.3 V on a MKR board) and off (0 Volts) by changing the portion of the time the signal spends on versus the time that the signal spends off. The duration of "on time" is called the pulse width. To get varying analog values, you change, or modulate, that pulse width. If you repeat this on-off pattern fast enough with an LED for example, the result is as if the signal is a steady voltage between 0 and Vcc controlling the brightness of the LED.  

In the graphic below, the green lines represent a regular time period. This duration or period is the inverse of the PWM frequency. In other words, with Arduino's PWM frequency at about 500Hz, the green lines would measure 2 milliseconds each. A call to analogWrite() is on a scale of 0 - 255, such that analogWrite(255) requests a 100% duty cycle (always on), and analogWrite(127) is a 50% duty cycle (on half the time) for example.

<p align="center">
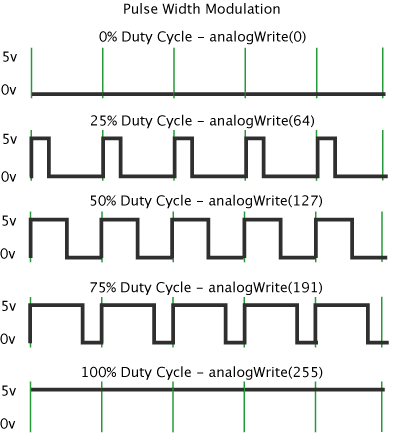
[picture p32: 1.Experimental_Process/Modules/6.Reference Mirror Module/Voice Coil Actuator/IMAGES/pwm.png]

</p>

Once you get this example running, grab your arduino and shake it back and forth. What you are doing here is essentially mapping time across the space. To our eyes, the movement blurs each LED blink into a line. As the LED fades in and out, those little lines will grow and shrink in length. Now you are seeing the pulse width.

[Source of the PWM page.](https://www.arduino.cc/en/Tutorial/Foundations/PWM)

A PWM Arduino tutorial for practice can be found [here](https://create.arduino.cc/projecthub/muhammad-aqib/arduino-pwm-tutorial-ae9d71) or secrets of PWM [in here.](https://www.arduino.cc/en/Tutorial/SecretsOfArduinoPWM)

## ESP-32S
ESP-32S is a

Follow [this page](https://github.com/openUC2/UC2-Software-GIT/tree/master/HARDWARE_CONTROL/ESP32) for ESP-32 seeting up using Arduino IDE.
Prepare your IDE to work with the ESP32 boards, as awesomely described [here.](https://randomnerdtutorials.com/installing-the-esp32-board-in-arduino-ide-windows-instructions/)

ESP32 PWM with Arduino IDE tutorial is explained in [this page](https://randomnerdtutorials.com/esp32-pwm-arduino-ide/) in detail.

### Components of the System

|  Type | Details  |  Amount | Price | Link  |
|---|---|---|---|---|
| Voice Coil Actuator | ** |  4  |  x,xx € | [Design File](./INVENTOR)  | [Part.stl](./STL/)  |
| Star LED Cage Holder Top |  *It covers top of the cage design* |  1  |  x,xx € | [Design File](./INVENTOR)  | [Part.stl](./STL/) |

### Connection of VCA with Microcontroller

*Connection Diagram of the ESP32 with transistor*

* GPIO pins supplies 20-40 mA maximum. Voice Coil Actuator needs higher startup current to drive it.
For this reason, we need to increase startup current adding a transistor between esp32 driver and VCA to increase the initial current for the VCA.

Diagram scheme is taken by the connection with a motor system. But it has the same connection (with second diagram) for VCA, transistor and ESP32 driver.
Follow 2nd diagram. Accept ESP32 as Arduino board and do not use resistor between ESP32 and transistor.
<p align="center">
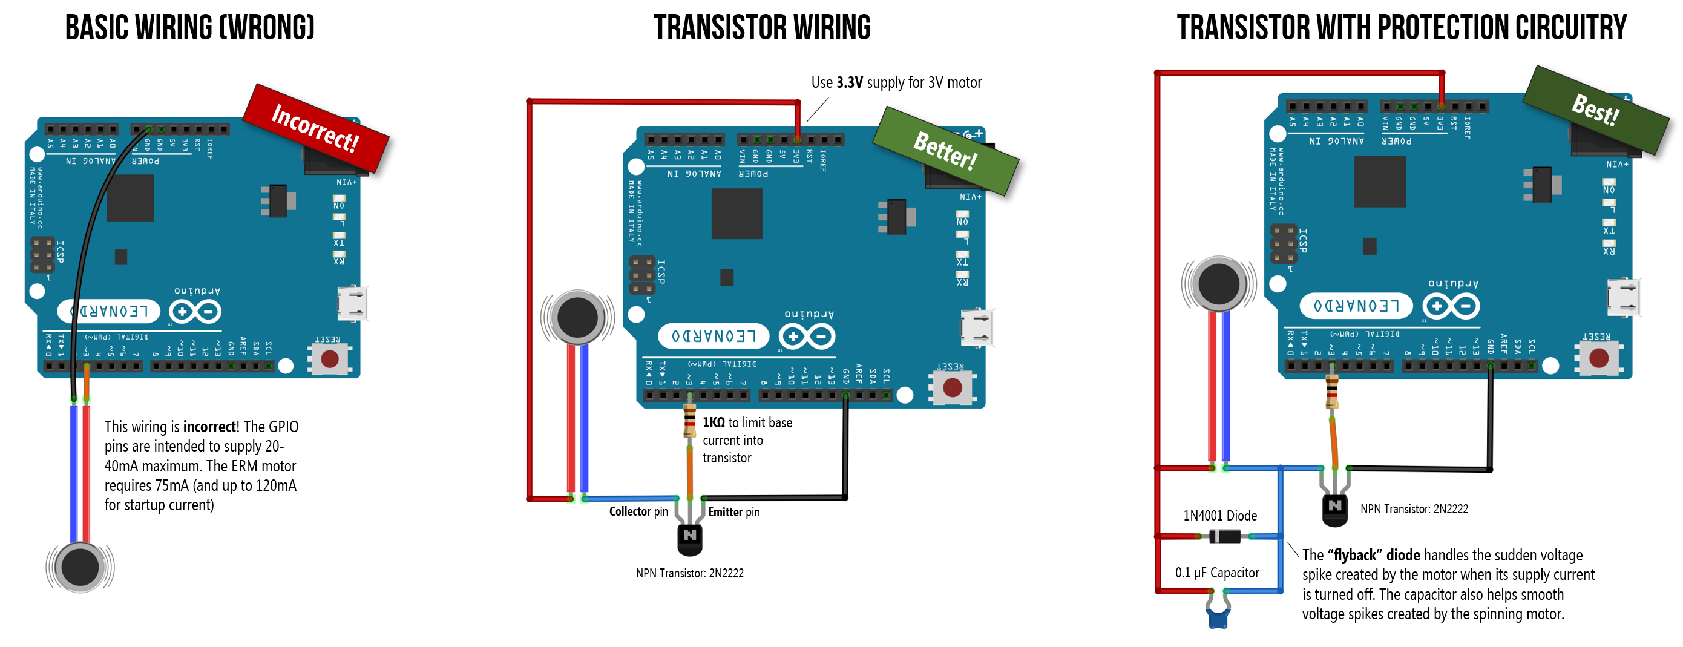
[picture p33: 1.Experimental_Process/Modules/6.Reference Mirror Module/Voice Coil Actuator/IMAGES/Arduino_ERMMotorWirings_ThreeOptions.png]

</p>

*Pin diagram of the ESP32:*  

<p align="center">

</p>

IO22 is our GPIO pin to control the mirror in z direction.     

*VCA lens soldering for z and x direction:*

<p align="center">

</p>

*The connection diagram of our VCA actuator with transistor and ESP32 driver:*    

__UPDATE__

<p align="center">

</p>

### Codes for controlling of VCA  
ESP32 Arduino code to connect WiFi and setting up z stage and pins of ESP32 driver. Code file is [here.](./Codes/ESP32_movelens.ipynb).

Steps to use VCA:
* check the pin numbers of esp32 with your connected pin numbers
* run the ESP32_movelens.ipynb Arduino code and activate WiFİ and connect the PC or smartphone.  
  name of the PC:  "Blynk"  
  PC password = "12345678"
* copy the IP adress of the ESP32 from PC after Connection
* open the jupyter notebook (anaconda terminal, type : jupyter-notebook)
* open the [python code](./Codes/REST_API_motor_lensxz_v0.ino) to control the mirror in z direction.
* update the IP address of the esp32 which you cpied from yhe PC settings
* run the code. You can control the mirror by changing the bar in *.....* steps. __(THIS INFO WILL BE ADDED AFTER CALCULATION)__

## Collaborating
If you find this project useful, please like this repository, follow us on Twitter and cite the webpage! :-)

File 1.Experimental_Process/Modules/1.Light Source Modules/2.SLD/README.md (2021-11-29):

# SLED or SLD (Superlumimescent Diode)

A superluminescent diode (SLED or SLD) is an edge-emitting semiconductor light source based on superluminescence. It combines the high power and brightness of laser diodes with the low coherence of conventional light-emitting diodes. (WIKI)
Some application areas are optical coherence tomography, white light interferometry, optical sensing and fibre optic gyroscopes.

In OCT systems, SLED is most used light source option because of its low coherence and high spatical coherence.

*Properties of the a proper SLED source for OCT system:*
* Low Coherence light source
* high Power
* high brightness

Some applications take advantage of the low temporal coherence of SLEDs sources to achieve high spatial resolution in imaging techniques.
*The coherence length*, L_c, is a quantity frequently used to characterize the temporal coherence of the light source. It is related to the path difference between the two arms of an optical interferometer over which the light wave is still capable to generate an interference pattern.
For sources having a Gaussian spectral distribution, the value of L_c is inversely proportional to the spectral width, BW, so that the full width at half maximum (FWHM) of the power spectral density can be related to L_c through the equation

L_c = (λ^2) / (B*W)

where λ (lambda) is the central wavelength of the emitted radiation.

As an example, an SLED operating around 1300 nm and with an optical bandwidth of 100 nm is expected to have a coherence length of about 17 μm. From a practical point of view a definition independent on the spectral distribution (non-Gaussian spectrum) of the source is more suitable.
If an optical interferometer is used for the coherence length evaluation a useful quantity is the FWHM value of the visibility, that is the relative amplitude [(Ipeak - Ivalley) / (Ipeak + Ivalley)] of the intensity variations evaluated as a function of the interferometer imbalance.

SLEDs exhibit a large spectral width even at the highest power levels so that corresponding FWHM values of the visibility less than **20 μm** are easily achieved. (WIKI)

<p align="middle">

</p>

## Collaborating
If you find this project useful, please like this repository, follow us on Twitter and cite the webpage! :-)

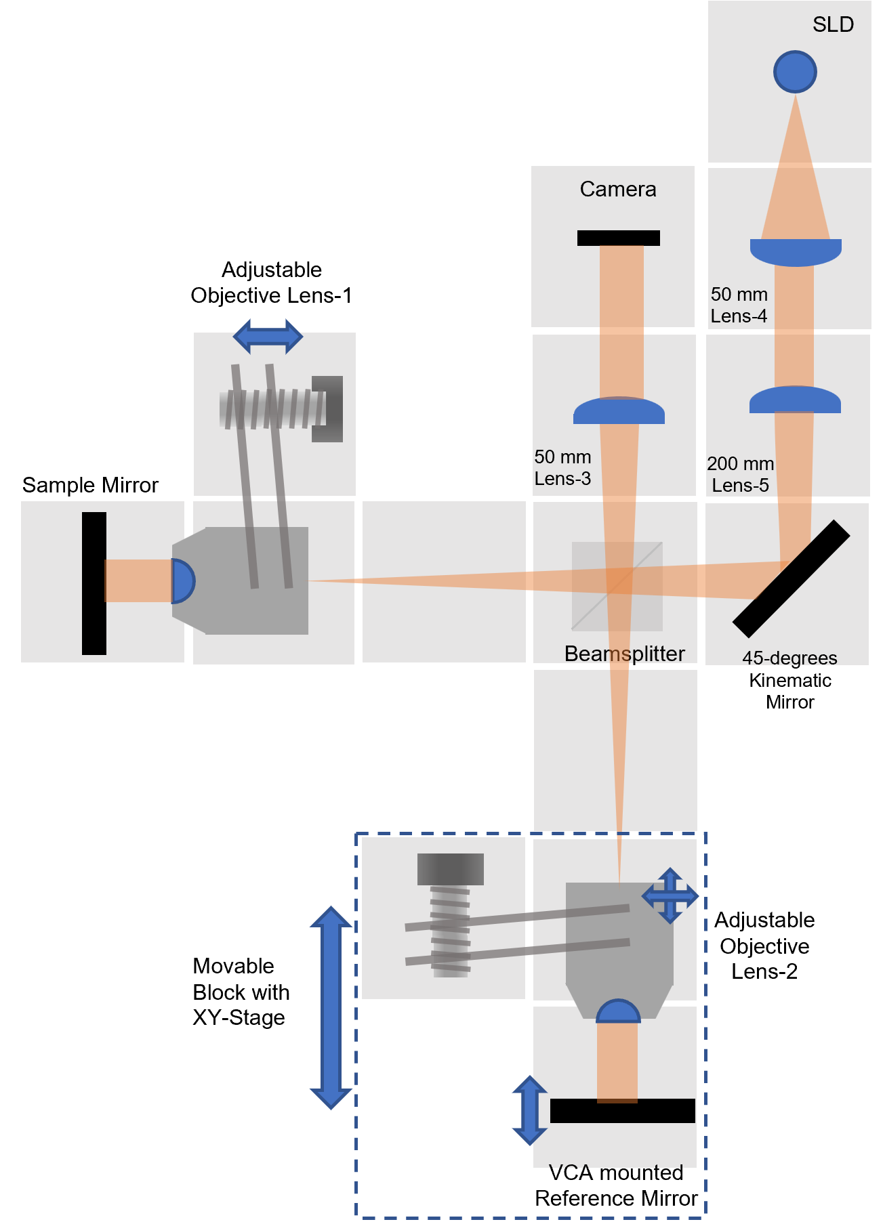
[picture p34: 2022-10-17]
1.Experimental_Process/Alignment_Procedure/IMAGES/algn_5.png

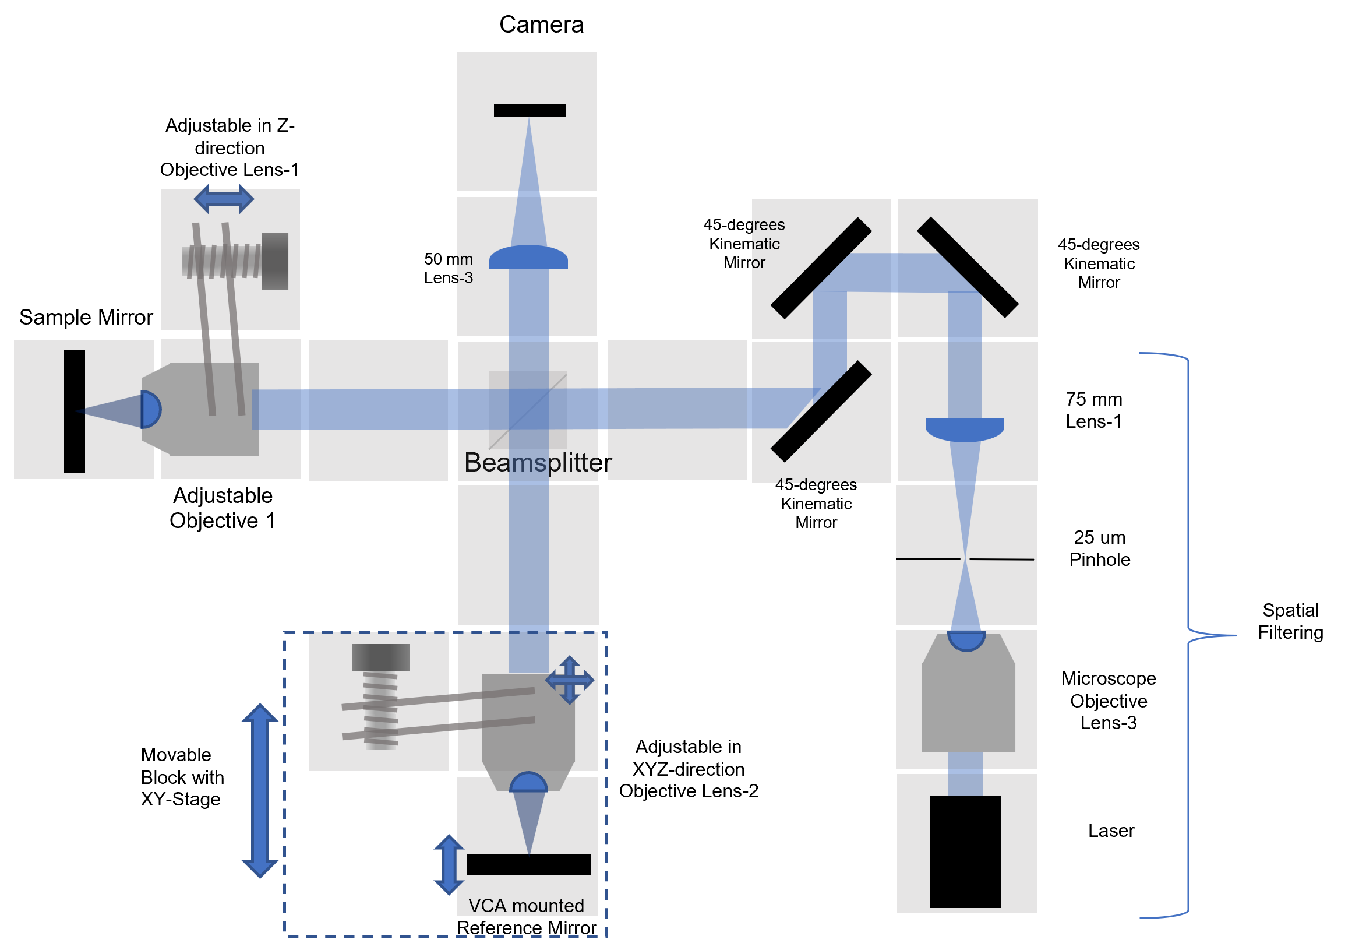
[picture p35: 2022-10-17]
1.Experimental_Process/Alignment_Procedure/IMAGES/algn_3.png

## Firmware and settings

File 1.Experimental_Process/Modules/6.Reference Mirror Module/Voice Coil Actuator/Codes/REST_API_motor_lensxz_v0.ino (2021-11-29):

#include <Arduino.h>
#include <WiFi.h>
#include <WebServer.h>
#include <ArduinoJson.h>

/*
 * 
import urllib
import cv2
import numpy as np

url='http://192.168.8.100/cam-hi.jpg'

while True:
    imgResp=urllib.request.urlopen(url)
    imgNp=np.array(bytearray(imgResp.read()),dtype=np.uint8)
    img=cv2.imdecode(imgNp,-1)

    # all the opencv processing is done here
    cv2.imshow('test',img)
    if ord('q')==cv2.waitKey(10):
        exit(0)
        
 */
#include <Stepper.h>
// Define number of steps per rotation:
const int stepsPerRevolution = 2 * 2048;
const int Nsteps = 10000;
Stepper stepper_x = Stepper(stepsPerRevolution, 4, 25, 32, 27);
Stepper stepper_y = Stepper(stepsPerRevolution, 26, 18, 19, 23);

// setting up wifi parameters
const char *SSID = "Blynk"; //"BenMur"; //
const char *PWD = "12345678"; // "MurBen3128";//
String hostname = "ESPLENS";

/*LASER GPIO pin*/
int LASER_PIN_PLUS = 27;// 22;
int LASER_PIN_MINUS = 0;//23;
int LED_PIN = 2;

/*Lens GPIO pins*/
int LENS_X_PIN = 21;
int LENS_Z_PIN = 22;

///* topics - DON'T FORGET TO REGISTER THEM! */
int LED_val = 0;
int LENS_X_val = 0;
int LENS_Z_val = 0;
int LENS_VIBRATE = 0;
int LASER_val = 0;
int LASER_val_2 = 0;
int STEPPER_Z_FWD = 0;
int STEPPER_Z_BWD = 0;
int LED_ARRAY_val = 0;
int LENS_X_SOFI = 0;
int LENS_Z_SOFI = 0;
int STATE = 0;
int STEPS = 200;
int SPEED = 0;

int lensval_x = 0;
int lensval_z = 0;
int laser_diff = 0;
// global switch for vibrating the lenses
int sofi_periode = 100;  // ms
int sofi_amplitude_x = 0;   // how many steps +/- ?
int sofi_amplitude_z = 0;   // how many steps +/- ?

// default values for x/z lens' positions
int lens_x_int = 0;
int lens_z_int = 0;
int laser_int = 0;
int lens_x_offset = 0;
int lens_z_offset = 0;//1000;

boolean is_sofi_x = false;
boolean is_sofi_z = false;

// PWM Stuff
int pwm_resolution = 15;
int pwm_frequency = 800000;//19000; //12000
int pwm_max = (int)pow(2, pwm_resolution);
// lens x-channel
int PWM_CHANNEL_X = 0;

// lens z-channel
int PWM_CHANNEL_Z = 1;

// laser-channel
int PWM_CHANNEL_LASER = 2;

// laser-channel
int PWM_CHANNEL_LASER_2 = 3;


// env variable
float temperature;

// Web server running on port 80
WebServer server(80);

// JSON data buffer
//StaticJsonDocument<2500> jsonDocument;
char buffer[2500];
DynamicJsonDocument jsonDocument(2048);


void setup() {
  Serial.begin(115200);

  // initiliaze connection
  connectToWiFi();
  setup_routing();

  /* set led and laser as output to control led on-off */
  pinMode(LED_PIN, OUTPUT);

  // switch of the laser directly
  pinMode(LASER_PIN_MINUS, OUTPUT);
  pinMode(LASER_PIN_MINUS, OUTPUT);
  digitalWrite(LASER_PIN_PLUS, LOW);
  digitalWrite(LASER_PIN_MINUS, LOW);

  // Visualize, that ESP is on!
  digitalWrite(LED_PIN, HIGH);
  delay(1000);
  digitalWrite(LED_PIN, LOW);

  /* setup the PWM ports and reset them to 0*/
  ledcSetup(PWM_CHANNEL_X, pwm_frequency, pwm_resolution);
  ledcAttachPin(LENS_X_PIN, PWM_CHANNEL_X);
  ledcWrite(PWM_CHANNEL_X, 0);

  ledcSetup(PWM_CHANNEL_Z, pwm_frequency, pwm_resolution);
  ledcAttachPin(LENS_Z_PIN, PWM_CHANNEL_Z);
  ledcWrite(PWM_CHANNEL_Z, 0);

  ledcSetup(PWM_CHANNEL_LASER, pwm_frequency, pwm_resolution);
  ledcAttachPin(LASER_PIN_PLUS, PWM_CHANNEL_LASER);
  ledcWrite(PWM_CHANNEL_LASER, 0);

  ledcWrite(PWM_CHANNEL_LASER_2, 0);

  // test lenses
  ledcWrite(PWM_CHANNEL_Z, 5000);
  ledcWrite(PWM_CHANNEL_X, 5000);
  delay(500);

  //Set the lenses to their offset level
  ledcWrite(PWM_CHANNEL_Z, lens_z_offset);
  ledcWrite(PWM_CHANNEL_X, lens_x_offset);

  Serial.println("Initialization finished.");


}

void loop() {
  server.handleClient();
}

void connectToWiFi() {
  Serial.print("Connecting to ");
  Serial.println(SSID);  
  WiFi.mode(WIFI_STA);
  WiFi.config(INADDR_NONE, INADDR_NONE, INADDR_NONE, INADDR_NONE);
  WiFi.setHostname(hostname.c_str()); //define hostname
  WiFi.begin(SSID, PWD);

  while (WiFi.status() != WL_CONNECTED) {
    Serial.print(".");
    delay(500);
    // we can even make the ESP32 to sleep
  }

  Serial.print("Connected. IP: ");
  Serial.println(WiFi.localIP());
}


/*

        RESTAPI RELATED


*/

void setup_routing() {
  // GET
  //  server.on("/temperature", getTemperature);
  //server.on("/env", getEnv);

  // POST
  server.on("/led", HTTP_POST, set_led);
  server.on("/move_x", HTTP_POST, move_x);
  server.on("/move_y", HTTP_POST, move_y);
  server.on("/lens_x", HTTP_POST, move_lens_x);
  server.on("/lens_z", HTTP_POST, move_lens_z);
  server.on("/laser", HTTP_POST, set_laser);

  // start server
  server.begin();
}

void create_json(char *tag, float value, char *unit) {
  jsonDocument.clear();
  jsonDocument["type"] = tag;
  jsonDocument["value"] = value;
  jsonDocument["unit"] = unit;
  serializeJson(jsonDocument, buffer);
}

void add_json_object(char *tag, float value, char *unit) {
  JsonObject obj = jsonDocument.createNestedObject();
  obj["type"] = tag;
  obj["value"] = value;
  obj["unit"] = unit;
}


/*
void getTemperature() {
  Serial.println("Get temperature");
  create_json("temperature", temperature, "°C");
  server.send(200, "application/json", buffer);
}
void getEnv() {
  Serial.println("Get env");
  jsonDocument.clear();
  add_json_object("temperature", temperature, "°C");
  serializeJson(jsonDocument, buffer);
  server.send(200, "application/json", buffer);
}
*/



/*


   Move Lenses


*/

void move_lens_x() {
  if (server.hasArg("plain") == false) {
    //handle error here
  }
  String body = server.arg("plain");
  Serial.println(body);
  deserializeJson(jsonDocument, body);


  // Get RGB components
  int value = jsonDocument["lens_value"];

  // apply a nonlinear look-up table
  int lensval = (int)(pow(((float)(value + lens_x_offset) / (float)pwm_max), 2) * (float)pwm_max);
  ledcWrite(PWM_CHANNEL_X, lensval);
  Serial.print("Lens (right) X is set to: ");
  Serial.print(lensval);
  Serial.println();

  // Respond to the client
  server.send(200, "application/json", "{}");
}


void move_lens_z() {
  if (server.hasArg("plain") == false) {
    //handle error here
  }
  String body = server.arg("plain");
  deserializeJson(jsonDocument, body);

  // Get RGB components
  int value = jsonDocument["lens_value"];

  // apply a nonlinear look-up table
  int lensval = (int)(pow(((float)(value + lens_x_offset) / (float)pwm_max), 2) * (float)pwm_max);
  ledcWrite(PWM_CHANNEL_Z, lensval);
  Serial.print("Lens (right) Z is set to: ");
  Serial.print(lensval);
  Serial.println();

  // Respond to the client
  server.send(200, "application/json", "{}");
}

/*
 * 
 * 
 *  Set Laser 
 * 
 */

void set_laser() {
  if (server.hasArg("plain") == false) {
    //handle error here
  }
  String body = server.arg("plain");
  deserializeJson(jsonDocument, body);

  // Get RGB components
  int value = jsonDocument["value"];

  // apply a nonlinear look-up table
  int laserval = (int)(pow(((float)(value) / (float)pwm_max), 2) * (float)pwm_max);
  ledcWrite(PWM_CHANNEL_LASER, laserval );
  Serial.print("Laser is set to: ");
  Serial.print(laserval);
  Serial.println();

  // Respond to the client
  server.send(200, "application/json", "{}");
}




/*

   Move Motors

*/

void move_x() {
  
  Serial.println("move_X");
  
  if (server.hasArg("plain") == false) {
    //handle error here
  }
  String body = server.arg("plain");
  deserializeJson(jsonDocument, body);

  // Get RGB components
  int steps = jsonDocument["steps"];
  int speed = jsonDocument["speed"];
  
  // Set the speed to 5 rpm:
  stepper_x.setSpeed(speed);

  Serial.print("steps x: ");
  Serial.print(steps);
  stepper_x.step(steps );

  // Respond to the client
  server.send(200, "application/json", "{}");
  
}




void move_y() {
  if (server.hasArg("plain") == false) {
    //handle error here
  }
  String body = server.arg("plain");
  deserializeJson(jsonDocument, body);

  // Get RGB components
  int steps = jsonDocument["steps"];
  int speed = jsonDocument["speed"];

  // Set the speed to 5 rpm:
  stepper_y.setSpeed(speed);

  Serial.print("steps y: ");
  Serial.print(steps);
  stepper_y.step(steps );

  // Respond to the client
  server.send(200, "application/json", "{}");
}





void set_led() {
  if (server.hasArg("plain") == false) {
    //handle error here
  }
  String body = server.arg("plain");
  deserializeJson(jsonDocument, body);

  // Get RGB components
  int red = jsonDocument["red"];
  int green = jsonDocument["green"];
  int blue = jsonDocument["blue"];
  Serial.print("Red: ");
  Serial.print(red);

  // Respond to the client
  server.send(200, "application/json", "{}");
}
